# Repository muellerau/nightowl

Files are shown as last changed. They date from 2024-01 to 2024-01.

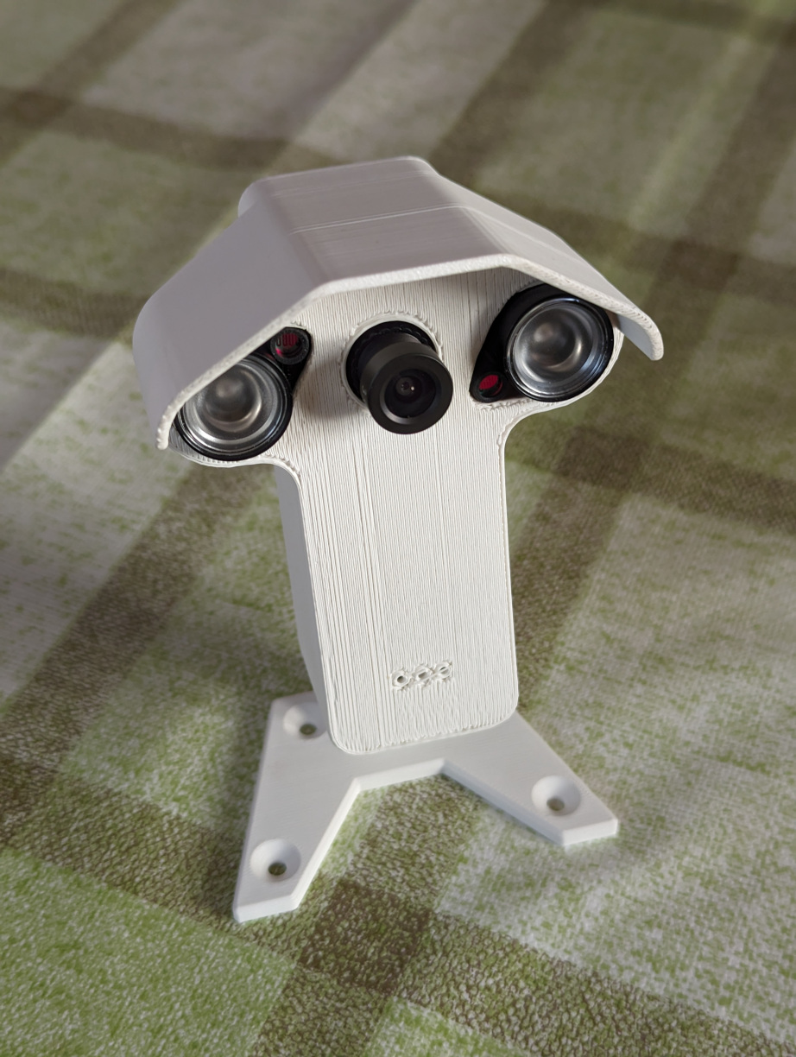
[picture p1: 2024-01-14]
images/assembly_final.jpg

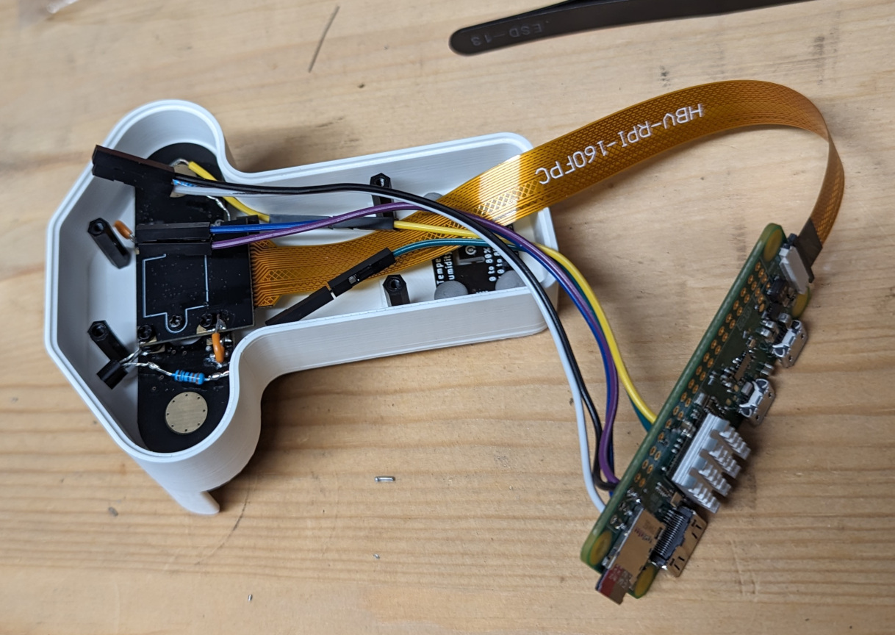
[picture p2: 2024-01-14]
images/assembly_cam-body.jpg

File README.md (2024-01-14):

# Nightowl

A small, lightweight infrared timelapse camera for wildlife and plant surveillance with temperature/humidity recording.
I built this for a family member so they can observe plant growth at night and detect pests.

## Materials

| line  | item | supplier | cat-no | quantity | $/item | $total | remarks |
| :---: | --- | --- | --- | :---: | :----: | :----: | --- |
| 1 | Raspberry Pi Zero W | PiShopUS | #808 | 1 | 15.00  | 15.00  | or better now, use Pi Zero 2W |
| 2 | microSD card 32GB or greater | any | any | 1 | ??? | ??? | I used a SanDisk 32GB Extreme Pro |
| 3 | DORHEA Camera Manual Focus 5MP OV5647 with 2x3W IR LED  | Amazon | B07JXZ93SK  | 1 | 15.99  | 15.99  | |
| 4 | Pi Zero Ribbon Cable Adapter 15CM 15 Pin to 22 Pin | Amazon | B0716TB6X3  | 1 | 5.99 | 5.99 | |
| 5 | R330 resistor | any | any | 2 | 0.00 | 0.00 | still had a few lying around |
| 6 | NPN BJT | onsemi/digikey  | PN2222 | 2 | 0.40 | 0.80 | |
| 7 | AHT20 | Adafruit | #4566 | 1 | 4.50 | 4.50 | |
| 8 | 3D printed housing | any | any | x | ??? | ??? | see below |
| 9 | M2 stand-offs (10mm male-female, 25mm female-female) + screws | Amazon | B0BXT4FG1T  | 1 | 9.99 | 9.99 | |
| 10 | 30 Ah USB power bank | any | any | 1 | ??? | ??? | any generic power bank with 2A or greater output will do |
| 11 | tesa Sugru | any | any | x | ??? | | used to isolate open wires, fix AHT20 and camera |

Regarding the housing/case in line 8: models for 3D printing are located in the 'case' folder; my design was loosely based on
https://www.thingiverse.com/thing:4741526
and the stand is identical (or use other mounts depending on application)
Note that I had some difficulty to fit the camera/LED module through the holes in the casing. Maybe the 3D print was a bit deformed or I made a mistake when calculating the dimensions, but a little bit of sanding resolved the issue.

## Wiring

The IR LEDs require a lot of power, but I wanted to be able to power the device with a battery/power bank. To minimize energy consumption, I included a small circuit to enable manual switching of the IR LEDs.

circuit sketch
BJT = onsemi PN2222

            LED(-) ------ BJT-C > BJT-B > BJT-E ----- 
             |||                   ^                |
            LED(+)                R330              |
              ^                    ^                |
            CAM(+)              GPIO pin7           |
    CSI------|||                                    |
            CAM(-)                                  |
              |                                     |
              ---------------------------------------

This was the test setup. In the end, I used GPIO pins 13 and 15 (physical numbering; BCM numbering is GPIO 27 and 22).

I did some measurements using a generic amp-meter (no guarantees for accuracy)
| routing | max current (mA) |
| --- | --- |
| GPIO pin7 -> R330 -> BJT-B | 9 |
| CAM(+) -> LED(+) | 140 (varies with photoresistor and potentiometer on LED) |

If the LED power consumption is too high, adjust the variable resistor on the LEDs.

## Assembly

Before assembly, the switching circuit for the IR LEDs should be soldered. Any open wires can be isolated using a moldable plastic glue (e.g., I used Sugru).

To mount the camera and Pi Zero in the case, stand-offs are needed (line 9 above):
- 4x 6mm female-female in the cam body to support camera (glue onto plastic pins around camera hole)
- place LEDs, place 2 washers over each mount hole, place camera on top, screw everything onto stand-off (this part is rather finicky)
- 4x 15mm female-female in the cam body to support the Pi Zero body (glue onto raised plastic pins)
- 4x 6mm male-female for the Pi Zero body to support the lid
- the lid is simply screwed on

The AHT20 (with header soldered on) can be mounted with small blobs of moldable plastic glue.

The case leaves space for a small heatsinks to be added to the camera/LEDs and the Pi Zero (max 5mm). However, I only used a heatsink on the Pi Zero.

## Dashboard Dependencies
Python modules: `flask` `picamera` `smbus2`

The dashboard incorporates Miguel Grinberg's camera live streaming driver (https://github.com/miguelgrinberg/flask-video-streaming/) with minor adjustments.

## Installation
- Install Raspbian image on the microSD card
- Clone the nightowlDashboard folder to the Pi Zero
- Set environment variable `CAMERA = pi`
- Change directory to the dashboard folder `cd /home/nightowl/nightowlDashboard`
- Start the dashboard as root with environment preservation: `sudo -E python3 app.py`

## Use as service
Establishing the flask webserver as a service will enable
- start on boot
- automatic restarts upon crash/failure
- journal logging

To do so,
- create a file `/etc/systemd/system/nightowl.service` with content
```
[Unit]
Description=Nightowl Web Application
After=network.target
StartLimitBurst=10
StartLimitIntervalSec=300

[Service]
User=root
WorkingDirectory=/home/nightowl/nightowlDashboard
Environment=CAMERA=pi
ExecStart=/bin/env python3 /home/nightowl/nightowlDashboard/app.py
Restart=always
RestartSec=30

[Install]
WantedBy=multi-user.target
```

- execute `sudo systemctl daemon-reload`
- check if it executes fine by `sudo systemctl start nightowl`
- status checks can be performed with `sudo systemctl status nightowl`
- the journal/log can be accessed through `journatctl -u nightowl`

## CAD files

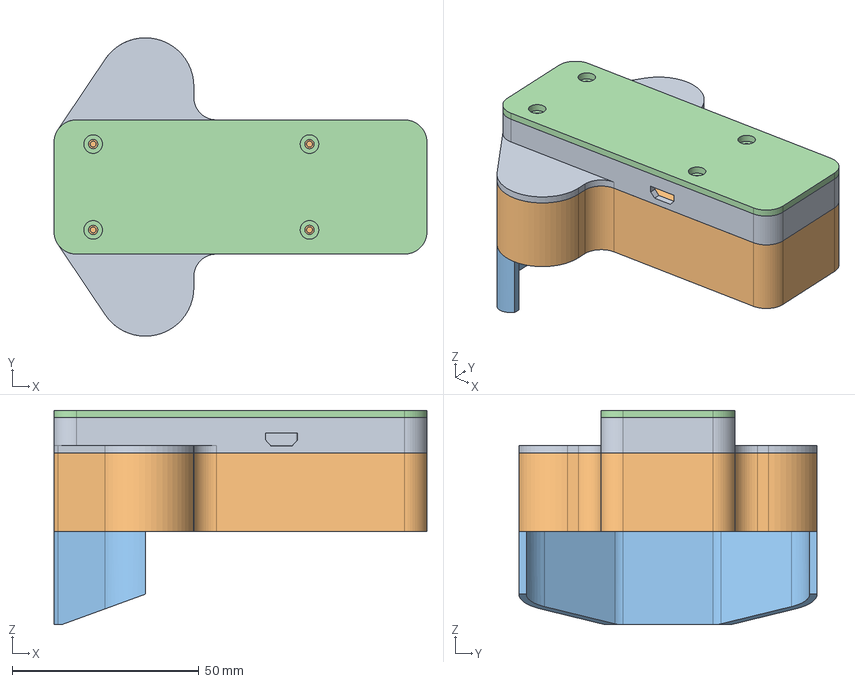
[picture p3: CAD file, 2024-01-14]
models/nightowl-case-v3.FCStd
100.0 x 80.0 x 57.5 mm

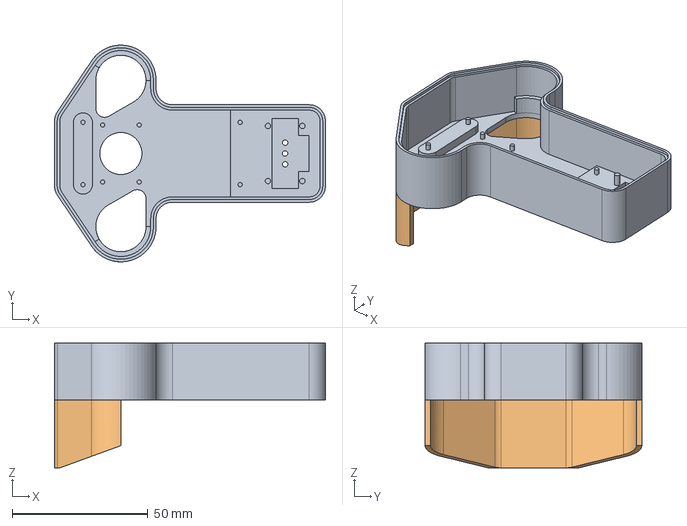
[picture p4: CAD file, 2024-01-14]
models/nightowl-case-v3-cam-body.step
100.0 x 80.0 x 46.0 mm

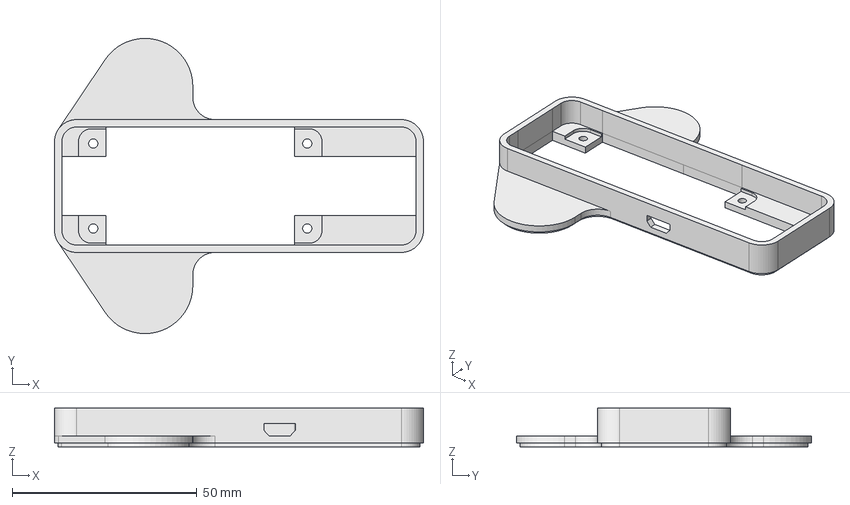
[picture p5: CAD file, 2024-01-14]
models/nightowl-case-v3-pizero-body.step
100.0 x 80.0 x 10.5 mm

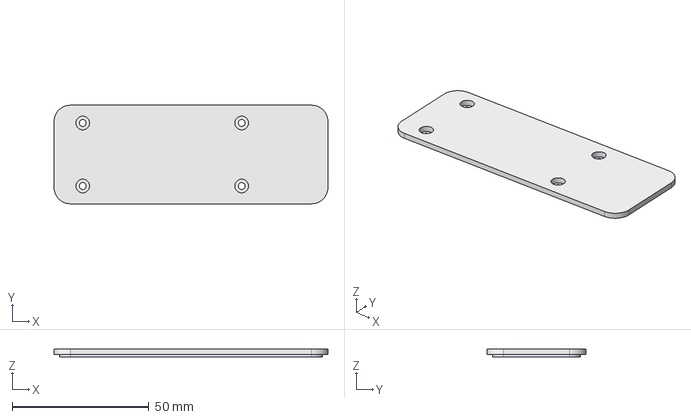
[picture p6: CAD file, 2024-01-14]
models/nightowl-case-v3-pizero-lid.step
100.0 x 36.0 x 3.00 mm

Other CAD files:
models/nightowl-case-v3-cam-body.stl
models/nightowl-case-v3-pizero-body.stl
models/nightowl-case-v3-pizero-lid.stl

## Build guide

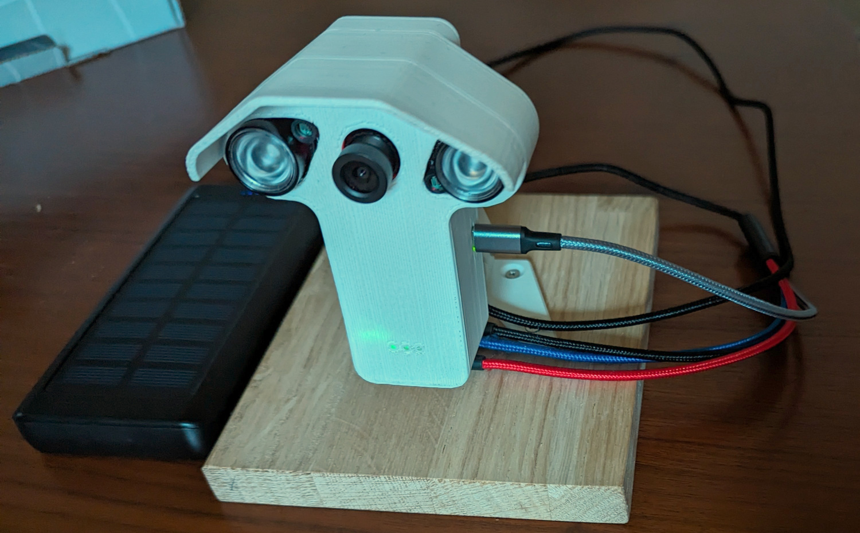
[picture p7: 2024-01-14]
images/assembly_final2.jpg

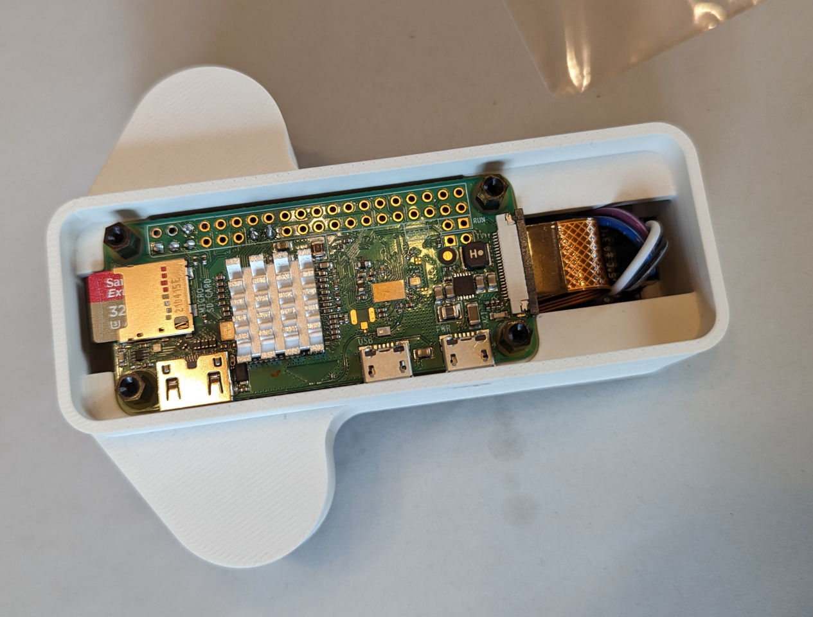
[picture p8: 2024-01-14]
images/assembly_pizero-body.jpg

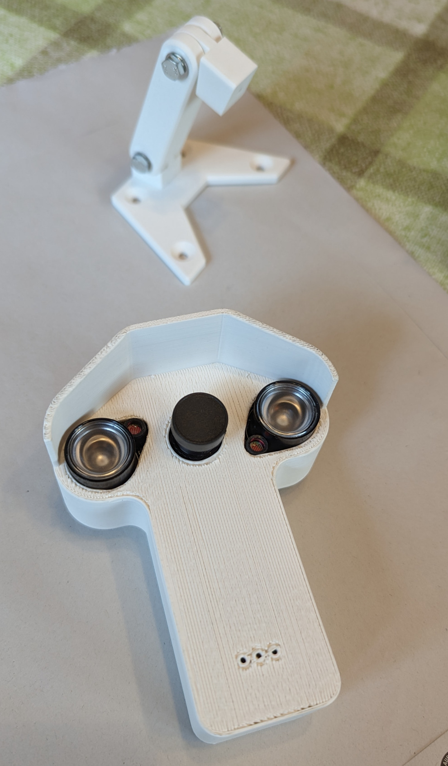
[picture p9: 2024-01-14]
images/assembly_front.jpg

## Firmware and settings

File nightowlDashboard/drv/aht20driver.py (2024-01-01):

#!/usr/bin/env python3

from smbus2 import SMBus
from time import time, sleep

# NOTE: smbus functions require a register byte which is referred to as command byte in the sensor datasheet and here;
#       data blocks can be read from register byte 0x00 (or any byte as it appears, although it seems preferable to avoid reading a command byte)

I2C_BUS_NUMBER  = 1     # I2C bus number (typically 1 for RPi devices)

AHT20_ADDRESS   = 0x38  # I2C address of AHT20
AHT20_INIT      = 0xBE  # initialization command, requires data bytes as per sensor specification, see below
#AHT20_INIT      = 0xE1  # this is the initialization command used by Adafruit
AHT20_TRIGGER   = 0xAC  # trigger measurement, requires data bytes as per sensor specification, see below
AHT20_RESET     = 0xBA  # soft reset command

AHT20_CAL       = 0x08  # calibration status byte; only used for cross-check in driver
AHT20_BUSY      = 0x80  # busy status byte; only used for cross-check in driver


# data bytes
# see AHT20 data sheet for reference
INIT_DATA01 = [0x08, 0x00]
TRIG_DATA01 = [0x33, 0x00]


class AHT20:
    def __init__(self, i2cbus: int = I2C_BUS_NUMBER) -> None:
        sleep(0.04) # wait for sensor self-init
        #self.i2cdevice = SMBus(i2cbus) # establish i2c bus connection
        self._buffer = [0] * 6
        self.reset() # reset sensor
        if not self.calibrate(): # check calibration state
            raise RuntimeError("AHT20: calibration failed")
        self._temp = None
        self._hum = None
    
    def reset(self) -> None:
        """ Soft reset sensor. """
        self._buffer[0] = AHT20_RESET
        with SMBus(I2C_BUS_NUMBER) as sens:
            sens.write_byte(AHT20_ADDRESS, self._buffer[0])
        sleep(0.02)
    
    def calibrate(self) -> bool:
        """ Manually intialize sensor and check calibration status. """
        self._buffer[0] = AHT20_INIT
        self._buffer[1:3] = INIT_DATA01
        self._busywait()
        with SMBus(I2C_BUS_NUMBER) as sens: # ask sensor to initialize
            sens.write_i2c_block_data(AHT20_ADDRESS, self._buffer[0], self._buffer[1:3])
        sleep(0.01)
        self._busywait()
        if not self.status & AHT20_CAL: # compute calibration status
            return False
        return True

    def _busywait(self) -> None:
        """ Internal helper function to wait for sensor action. """
        self._now = time()
        while self.status & AHT20_BUSY: # check if busy
            sleep(0.02)
            if (time() - self._now) > 10:
                raise RuntimeError("AHT20: aborted - received busy signal for 10 seconds")

    @property
    def status(self) -> int:
        """ Obtains status byte from sensor. """
        with SMBus(I2C_BUS_NUMBER) as sens:
            self._buffer[5] = sens.read_byte(AHT20_ADDRESS)
        return self._buffer[5]

    @property
    def temperature(self) -> int:
        #self.measure()
        return self._temp
    
    @property
    def humidity(self) -> int:
        #self.measure()
        return self._hum
    
    def measure(self) -> None:
        self._buffer[0] = AHT20_TRIGGER
        self._buffer[1:3] = TRIG_DATA01
        self._busywait()
        with SMBus(I2C_BUS_NUMBER) as sens:
            sens.write_i2c_block_data(AHT20_ADDRESS, self._buffer[0], self._buffer[1:3])
        self._busywait()
        with SMBus(I2C_BUS_NUMBER) as sens:
            self._buffer = sens.read_i2c_block_data(AHT20_ADDRESS, 0x00, 6) # read six bytes (1 status byte + 5 data bytes)
        self._hum = ((
            (self._buffer[1] << 12) | (self._buffer[2] << 4) | (self._buffer[3] >> 4) # stitch humidity data bytes together
            ) / 2**20) * 100 # convert humidity data; refer to data sheet for details
        self._temp = ((
            ((self._buffer[3] & 0xF) << 16) | (self._buffer[4] << 8) | self._buffer[5] # stitch temperature data bytes together
            ) / 2**20) * 200 - 50 # convert temperature data; refer to data sheet for details

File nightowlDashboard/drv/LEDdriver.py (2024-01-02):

#!/usr/bin/env python3

import RPi.GPIO as GPIO


IR_LED_PINS = (13,15)

class IReyes:
    def __init__(self) -> None:
        GPIO.setmode(GPIO.BOARD)
        for p in IR_LED_PINS:
            GPIO.setup(p, GPIO.OUT)
        self._state = 0

    def toggle(self) -> None:
        for p in IR_LED_PINS:
            GPIO.output(p, not GPIO.input(p))
            self._state = self._state & GPIO.input(p)

    def turn_on(self) -> None:
        self._state = 1
        for p in IR_LED_PINS:
            GPIO.output(p, 1)

    def turn_off(self) -> None:
        self._state = 0
        for p in IR_LED_PINS:
            GPIO.output(p, 0)

    def cleanup(self) -> None:
        GPIO.cleanup()

    @property
    def status(self):
        return self._state

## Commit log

2024-01-02 fixed shebang python -> python3
    [LEDdriver.py]
2024-01-04 major functionality update: timelapse page, timelapse functions, clena IR LED control exit
2024-01-04 fixed ir_light naming mistakes
    [timelapse.py]
2024-01-04 fixed livepage infrared switching
2024-01-04 running timelapse in thread
2024-01-05 debugged timelapse threading
2024-01-05 formatting of current timelapse parameters
2024-01-05 changed camera resolution to 854x480
2024-01-06 added frame timestamp
2024-01-06 fixed wrong stop function call
    [timelapse.py]
2024-01-06 fixed timelapse conversion code mistakes
    [timelapse.py]
2024-01-06 fixed slow capture code mistakes
    [timelapse.py]
2024-01-07 added poweroff functionality
2024-01-07 fixed wait cycle abort
    [timelapse.py]
2024-01-08 fixed tmp folder for ffmpeg
    [timelapse.py]
2024-01-08 fixed list selector in tmp deletion function to delete oldest files first
    [timelapse.py]
2024-01-14 added 3D print models
    [nightowl-case-v3-cam-body.step, nightowl-case-v3-cam-body.stl, nightowl-case-v3-pizero-body.step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]
2024-01-14 updated materials list
2024-01-14 added FreeCAD file
    [nightowl-case-v3.FCStd]
2024-01-14 added wiring info
2024-01-14 renamed folder
    [nightowl-case-v3-cam-body.step, nightowl-case-v3-cam-body.stl, nightowl-case-v3-pizero-body.step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]
2024-01-14 added assembly images
2024-01-14 added assembly description
2024-06-01 calculate camera capture wait time/frame steps based on time difference
2024-06-01 fixed time difference calculation
    [timelapse.py]
